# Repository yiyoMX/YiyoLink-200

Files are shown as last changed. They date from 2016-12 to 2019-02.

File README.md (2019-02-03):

# YiyoLink-200
TI CC1111 BLE BRIDGE

What is it?
A SMART Bluetooth 4.2 LE module based on nrf51822, it allows for a Texas Instruments CC-1111 USB DNGL to communicate to any BLE compatible device. It can act as a transparent UART bridge.

How does it works?
Simply plug in the CC-1111 with the header pins. You could also plug jumper wires to connect any device via UART. Can flash firmware to BLE module via OTA, using an Iphone.

Features?
- TI-CC1111 header pins compatible socket.
- 2-pin JST-PH battery connector.
- Micro USB Lithium-ion battery charger.
- Charging led indicator (goes off when fully charged).
- Smart BLE 4.2 BMD-200.
- BLE connected indicator.
- On/Off switch.
- Exposed pwr pads to solder external charging source. (wireless charging? - not tested)
- Small footprint.

Limitations.
-Due to the version of BLE, only 20 bytes are allowed per write.

How does it looks?
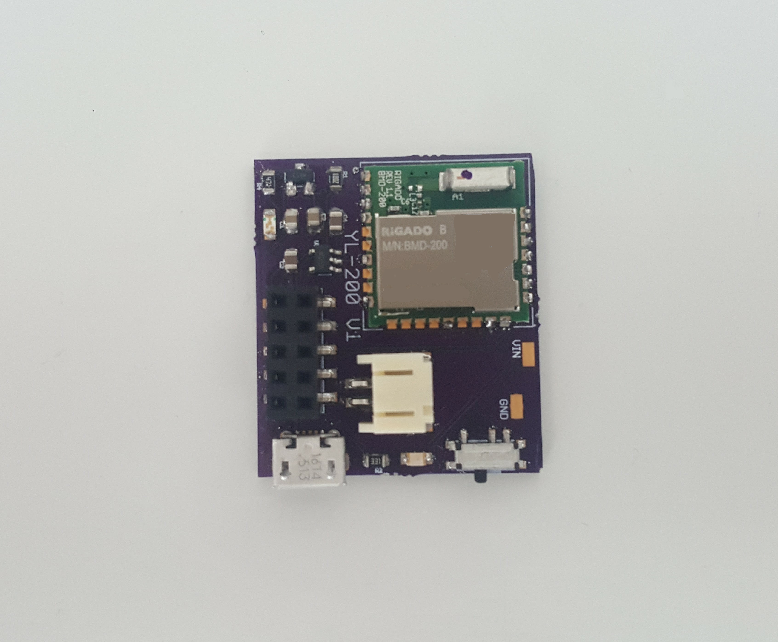
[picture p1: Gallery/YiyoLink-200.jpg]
YiyoLink-200-v1


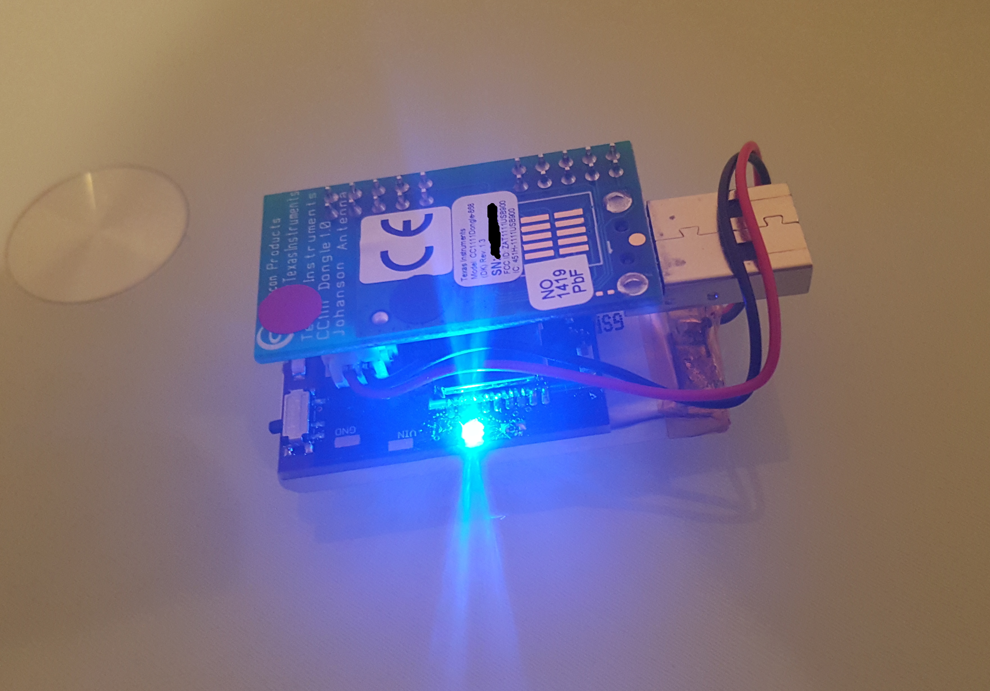
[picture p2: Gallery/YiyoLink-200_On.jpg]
YiyoLink-200 On


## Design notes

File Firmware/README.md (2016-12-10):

This is the firmware for the BLE module. It acts as a transparent UART bridge.

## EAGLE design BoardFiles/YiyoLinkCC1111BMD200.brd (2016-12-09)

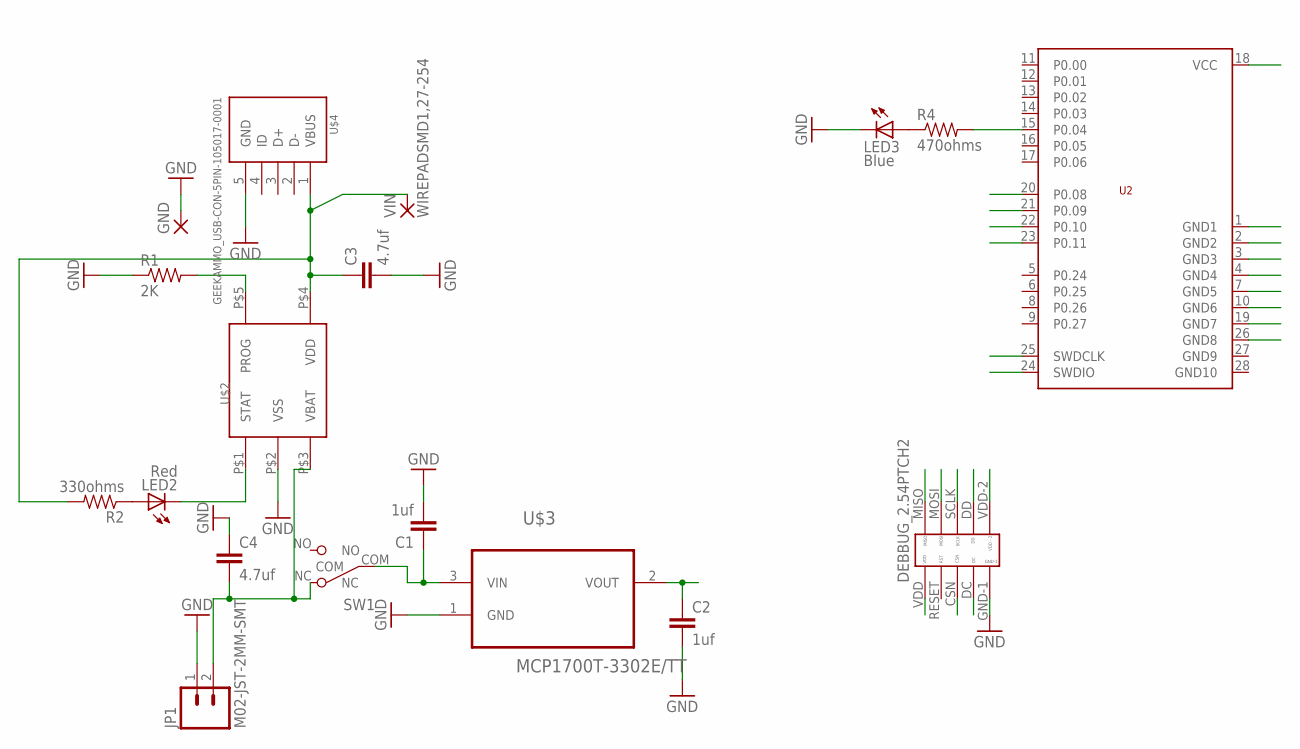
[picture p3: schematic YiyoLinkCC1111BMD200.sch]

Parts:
C1, C2: 1uf; 0805-CAP
C3, C4: 4.7uf; 0805
DEBBUG_2.54PTCH2: YIYOSLIBRARY_5X2_HEADER; YIYOSLIBRARY_5X2_FEMALE_HEADER
GND: WIREPADSMD1,27-254; SMD1,27-2,54
JP1: M02-JST-2MM-SMT; JST-2-SMD
LED2: Red; SML0805
LED3: Blue; SML0805
R1: 2K; 0805
R2: 330ohms; 0805
R4: 470ohms; 0805
SW1: SW_SLIDE; SLIDE_SWITCH_SMD
U2: BMD-200
U$2: MCP73831; 5PIN_SOT23
U$3: MCP1700T-3302E/TT; SOT95P237X112-3N
U$4: GEEKAMMO_USB-CON-5PIN-105017-0001; GEEKAMMO_USB-MICRO-MOLEX-105017-0001
VIN: WIREPADSMD1,27-254; SMD1,27-2,54

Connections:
CSN: DEBBUG_2.54PTCH2.CSN, U2.20 (P0.08)
DC: DEBBUG_2.54PTCH2.DC, U2.25 (SWDCLK)
DD: DEBBUG_2.54PTCH2.DD, U2.24 (SWDIO)
GND: C1.2, C2.2, C3.2, C4.1, DEBBUG_2.54PTCH2.GND-1, GND.1, JP1.1 (2), LED3.C, R1.1, U2.1 (GND1), U2.2 (GND2), U2.3 (GND3), U2.4 (GND4), U2.7 (GND5), U2.10 (GND6), U2.19 (GND7), U2.26 (GND8), U$2.P$2 (VSS), U$3.1 (GND), U$4.5 (GND)
MISO: DEBBUG_2.54PTCH2.MISO, U2.22 (P0.10)
MOSI: DEBBUG_2.54PTCH2.MOSI, U2.21 (P0.09)
unnamed: LED3.A, R4.1
unnamed: R4.2, U2.15 (P0.04)
unnamed: LED2.A, R2.1
unnamed: C3.1, R2.2, U$2.P$4 (VDD), U$4.1 (VBUS), VIN.1
unnamed: R1.2, U$2.P$5 (PROG)
unnamed: C4.2, JP1.2 (1), SW1.NC, U$2.P$3 (VBAT)
unnamed: C1.1, SW1.COM, U$3.3 (VIN)
unnamed: LED2.C, U$2.P$1 (STAT)
SCLK: DEBBUG_2.54PTCH2.SCLK, U2.23 (P0.11)
VDDO: C2.1, DEBBUG_2.54PTCH2.VDD, DEBBUG_2.54PTCH2.VDD-2, U2.18 (VCC), U$3.2 (VOUT)

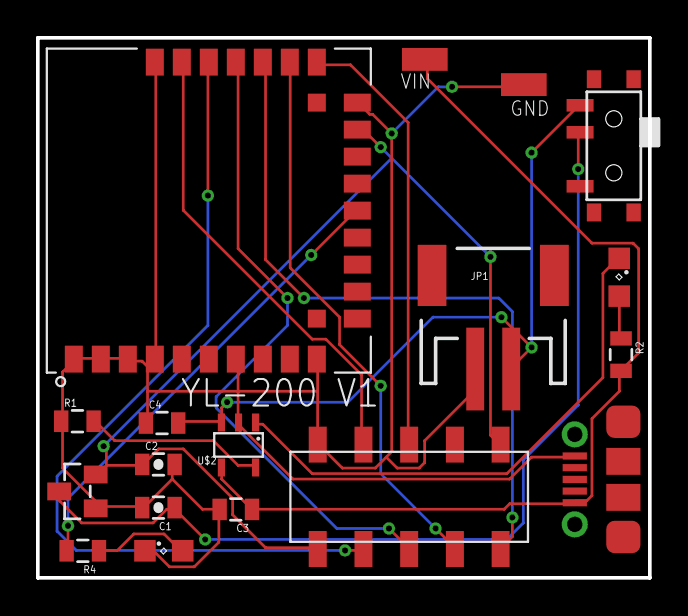
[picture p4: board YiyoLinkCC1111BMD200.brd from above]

Board: 2 copper layers, 34.0 x 30.0 mm, 18 parts (0 on the bottom side), 16 nets.

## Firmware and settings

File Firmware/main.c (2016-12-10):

/* Copyright (c) 2014 Nordic Semiconductor. All Rights Reserved.
 *
 * The information contained herein is property of Nordic Semiconductor ASA.
 * Terms and conditions of usage are described in detail in NORDIC
 * SEMICONDUCTOR STANDARD SOFTWARE LICENSE AGREEMENT.
 *
 * Licensees are granted free, non-transferable use of the information. NO
 * WARRANTY of ANY KIND is provided. This heading must NOT be removed from
 * the file.
 *
 */

/** @file
 *
 * @defgroup ble_sdk_app_template_main main.c
 * @{
 * @ingroup ble_sdk_app_template
 * @brief Template project main file.
 *
 * This file contains a template for creating a new application. It has the code necessary to wakeup
 * from button, advertise, get a connection restart advertising on disconnect and if no new
 * connection created go back to system-off mode.
 * It can easily be used as a starting point for creating a new application, the comments identified
 * with 'YOUR_JOB' indicates where and how you can customize.
 */

#include <stdint.h>
#include <string.h>
#include "nordic_common.h"
#include "nrf.h"
#include "app_error.h"
#include "ble.h"
#include "ble_hci.h"
#include "ble_srv_common.h"
#include "ble_advdata.h"
#include "ble_advertising.h"
#include "ble_conn_params.h"
#include "boards.h"
#include "softdevice_handler.h"
#include "app_timer.h"
#include "device_manager.h"
#include "pstorage.h"
#include "app_trace.h"
#include "bsp.h"
#include "bsp_btn_ble.h"

//Agregadas
#include "ble_nus.h"
#include "app_uart.h"

#define IS_SRVC_CHANGED_CHARACT_PRESENT  1                                          /**< Include or not the service_changed characteristic. if not enabled, the server's database cannot be changed for the lifetime of the device*/
#define CONNECTED_LED_PIN_NO 			BSP_LED_0
#define DEVICE_NAME                      "Yiyo-Link_200-TEST"                            /**< Name of device. Will be included in the advertising data. */
#define MANUFACTURER_NAME                "NordicSemiconductor"                      /**< Manufacturer. Will be passed to Device Information Service. */
#define APP_ADV_INTERVAL                 300                                        /**< The advertising interval (in units of 0.625 ms. This value corresponds to 25 ms). */
#define APP_ADV_TIMEOUT_IN_SECONDS       0                                       /**< The advertising timeout in units of seconds. */

#define APP_TIMER_PRESCALER              0                                          /**< Value of the RTC1 PRESCALER register. */
#define APP_TIMER_OP_QUEUE_SIZE          4                                          /**< Size of timer operation queues. */

#define MIN_CONN_INTERVAL                MSEC_TO_UNITS(100, UNIT_1_25_MS)           /**< Minimum acceptable connection interval (0.1 seconds). */
#define MAX_CONN_INTERVAL                MSEC_TO_UNITS(200, UNIT_1_25_MS)           /**< Maximum acceptable connection interval (0.2 second). */
#define SLAVE_LATENCY                    0                                          /**< Slave latency. */
#define CONN_SUP_TIMEOUT                 MSEC_TO_UNITS(4000, UNIT_10_MS)            /**< Connection supervisory timeout (4 seconds). */

#define FIRST_CONN_PARAMS_UPDATE_DELAY   APP_TIMER_TICKS(5000, APP_TIMER_PRESCALER) /**< Time from initiating event (connect or start of notification) to first time sd_ble_gap_conn_param_update is called (5 seconds). */
#define NEXT_CONN_PARAMS_UPDATE_DELAY    APP_TIMER_TICKS(30000, APP_TIMER_PRESCALER)/**< Time between each call to sd_ble_gap_conn_param_update after the first call (30 seconds). */
#define MAX_CONN_PARAMS_UPDATE_COUNT     3                                          /**< Number of attempts before giving up the connection parameter negotiation. */

#define SEC_PARAM_BOND                   0                                          /**< Perform bonding. */
#define SEC_PARAM_MITM                   0                                          /**< Man In The Middle protection not required. */
#define SEC_PARAM_IO_CAPABILITIES        BLE_GAP_IO_CAPS_NONE                       /**< No I/O capabilities. */
#define SEC_PARAM_OOB                    0                                          /**< Out Of Band data not available. */
#define SEC_PARAM_MIN_KEY_SIZE           7                                          /**< Minimum encryption key size. */
#define SEC_PARAM_MAX_KEY_SIZE           16                                         /**< Maximum encryption key size. */

#define START_STRING                    "Start.."

#define DEAD_BEEF                        0xDEADBEEF                                 /**< Value used as error code on stack dump, can be used to identify stack location on stack unwind. */

#define UART_TX_BUF_SIZE                256                                         /**< UART TX buffer size. */
#define UART_RX_BUF_SIZE                256                                         /**< UART RX buffer size. */

static dm_application_instance_t        m_app_handle;                               /**< Application identifier allocated by device manager */
static ble_nus_t                        m_nus; 																			/**< Structure to identify the Nordic UART Service. */
static uint16_t                          m_conn_handle = BLE_CONN_HANDLE_INVALID;   /**< Handle of the current connection. */

/* YOUR_JOB: Declare all services structure your application is using
static ble_xx_service_t                     m_xxs;
static ble_yy_service_t                     m_yys;
*/

// YOUR_JOB: Use UUIDs for service(s) used in your application.
static ble_uuid_t m_adv_uuids[] = {{BLE_UUID_DEVICE_INFORMATION_SERVICE, BLE_UUID_TYPE_BLE}}; /**< Universally unique service identifiers. */

                                   
/**@brief Callback function for asserts in the SoftDevice.
 *
 * @details This function will be called in case of an assert in the SoftDevice.
 *
 * @warning This handler is an example only and does not fit a final product. You need to analyze
 *          how your product is supposed to react in case of Assert.
 * @warning On assert from the SoftDevice, the system can only recover on reset.
 *
 * @param[in] line_num   Line number of the failing ASSERT call.
 * @param[in] file_name  File name of the failing ASSERT call.
 */
void assert_nrf_callback(uint16_t line_num, const uint8_t * p_file_name)
{
    app_error_handler(DEAD_BEEF, line_num, p_file_name);
}


/**@brief Function for the Timer initialization.
 *
 * @details Initializes the timer module. This creates and starts application timers.
 */
static void timers_init(void)
{

    // Initialize timer module.
    APP_TIMER_INIT(APP_TIMER_PRESCALER, APP_TIMER_OP_QUEUE_SIZE, false);

    // Create timers.

    /* YOUR_JOB: Create any timers to be used by the application.
                 Below is an example of how to create a timer.
                 For every new timer needed, increase the value of the macro APP_TIMER_MAX_TIMERS by
                 one.
    uint32_t err_code;
    err_code = app_timer_create(&m_app_timer_id, APP_TIMER_MODE_REPEATED, timer_timeout_handler);
    APP_ERROR_CHECK(err_code); */
}


/**@brief Function for the GAP initialization.
 *
 * @details This function sets up all the necessary GAP (Generic Access Profile) parameters of the
 *          device including the device name, appearance, and the preferred connection parameters.
 */
static void gap_params_init(void)
{
    uint32_t                err_code;
    ble_gap_conn_params_t   gap_conn_params;
    ble_gap_conn_sec_mode_t sec_mode;

    BLE_GAP_CONN_SEC_MODE_SET_OPEN(&sec_mode);

    err_code = sd_ble_gap_device_name_set(&sec_mode,
                                          (const uint8_t *)DEVICE_NAME,
                                          strlen(DEVICE_NAME));
    APP_ERROR_CHECK(err_code);

    /* YOUR_JOB: Use an appearance value matching the application's use case.
    err_code = sd_ble_gap_appearance_set(BLE_APPEARANCE_);
    APP_ERROR_CHECK(err_code); */

    memset(&gap_conn_params, 0, sizeof(gap_conn_params));

    gap_conn_params.min_conn_interval = MIN_CONN_INTERVAL;
    gap_conn_params.max_conn_interval = MAX_CONN_INTERVAL;
    gap_conn_params.slave_latency     = SLAVE_LATENCY;
    gap_conn_params.conn_sup_timeout  = CONN_SUP_TIMEOUT;

    err_code = sd_ble_gap_ppcp_set(&gap_conn_params);
    APP_ERROR_CHECK(err_code);
}


/**@brief Function for handling the YYY Service events. 
 * YOUR_JOB implement a service handler function depending on the event the service you are using can generate
 *
 * @details This function will be called for all YY Service events which are passed to
 *          the application.
 *
 * @param[in]   p_yy_service   YY Service structure.
 * @param[in]   p_evt          Event received from the YY Service.
 *
 *
static void on_yys_evt(ble_yy_service_t     * p_yy_service, 
                       ble_yy_service_evt_t * p_evt)
{
    switch (p_evt->evt_type)
    {
        case BLE_YY_NAME_EVT_WRITE:
            APPL_LOG("[APPL]: charact written with value %s. \r\n", p_evt->params.char_xx.value.p_str);
            break;
        
        default:
            // No implementation needed.
            break;
    }
}*/

/**@brief Function for handling the data from the Nordic UART Service.
 *
 * @details This function will process the data received from the Nordic UART BLE Service and send
 *          it to the UART module.
 *
 * @param[in] p_nus    Nordic UART Service structure.
 * @param[in] p_data   Data to be send to UART module.
 * @param[in] length   Length of the data.
 */
/**@snippet [Handling the data received over BLE] */
static void nus_data_handler(ble_nus_t * p_nus, uint8_t * p_data, uint16_t length)
{
//		nrf_gpio_pin_toggle(CONNECTED_LED_PIN_NO);
    for (uint32_t i = 0; i < length; i++)
    {
//        while(app_uart_put(p_data[i]) != NRF_SUCCESS);
			app_uart_put(p_data[i]);
    }
//    while(app_uart_put('\n') != NRF_SUCCESS);
}
/**@snippet [Handling the data received over BLE] */
/**@brief Function for initializing services that will be used by the application.
 */


static void services_init(void)
{
	uint32_t       err_code;
		
    ble_nus_init_t nus_init;
		memset(&nus_init, 0, sizeof(nus_init));

    nus_init.data_handler = nus_data_handler;
    
    err_code = ble_nus_init(&m_nus, &nus_init);
    APP_ERROR_CHECK(err_code);
    /* YOUR_JOB: Add code to initialize the services used by the application.
    uint32_t                           err_code;
    ble_xxs_init_t                     xxs_init;
    ble_yys_init_t                     yys_init;

    // Initialize XXX Service.
    memset(&xxs_init, 0, sizeof(xxs_init));

    xxs_init.evt_handler                = NULL;
    xxs_init.is_xxx_notify_supported    = true;
    xxs_init.ble_xx_initial_value.level = 100; 
    
    err_code = ble_bas_init(&m_xxs, &xxs_init);
    APP_ERROR_CHECK(err_code);

    // Initialize YYY Service.
    memset(&yys_init, 0, sizeof(yys_init));
    yys_init.evt_handler                  = on_yys_evt;
    yys_init.ble_yy_initial_value.counter = 0;

    err_code = ble_yy_service_init(&yys_init, &yy_init);
    APP_ERROR_CHECK(err_code);
    */
}


void uart_putstring(const uint8_t * str)

{

    uint32_t err_code;
    uint8_t len = strlen((char *) str);
    for (uint8_t i = 0; i < len; i++)
    {
        err_code = app_uart_put(str[i]);
        APP_ERROR_CHECK(err_code);
    }
}

/**@brief Function for handling the Connection Parameters Module.
 *
 * @details This function will be called for all events in the Connection Parameters Module which
 *          are passed to the application.
 *          @note All this function does is to disconnect. This could have been done by simply
 *                setting the disconnect_on_fail config parameter, but instead we use the event
 *                handler mechanism to demonstrate its use.
 *
 * @param[in] p_evt  Event received from the Connection Parameters Module.
 */
static void on_conn_params_evt(ble_conn_params_evt_t * p_evt)
{
    uint32_t err_code;

    if (p_evt->evt_type == BLE_CONN_PARAMS_EVT_FAILED)
    {
        err_code = sd_ble_gap_disconnect(m_conn_handle, BLE_HCI_CONN_INTERVAL_UNACCEPTABLE);
        APP_ERROR_CHECK(err_code);
    }
}


/**@brief Function for handling a Connection Parameters error.
 *
 * @param[in] nrf_error  Error code containing information about what went wrong.
 */
static void conn_params_error_handler(uint32_t nrf_error)
{
    APP_ERROR_HANDLER(nrf_error);
}


/**@brief Function for initializing the Connection Parameters module.
 */
static void conn_params_init(void)
{
    uint32_t               err_code;
    ble_conn_params_init_t cp_init;

    memset(&cp_init, 0, sizeof(cp_init));

    cp_init.p_conn_params                  = NULL;
    cp_init.first_conn_params_update_delay = FIRST_CONN_PARAMS_UPDATE_DELAY;
    cp_init.next_conn_params_update_delay  = NEXT_CONN_PARAMS_UPDATE_DELAY;
    cp_init.max_conn_params_update_count   = MAX_CONN_PARAMS_UPDATE_COUNT;
    cp_init.start_on_notify_cccd_handle    = BLE_GATT_HANDLE_INVALID;
    cp_init.disconnect_on_fail             = false;
    cp_init.evt_handler                    = on_conn_params_evt;
    cp_init.error_handler                  = conn_params_error_handler;

    err_code = ble_conn_params_init(&cp_init);
    APP_ERROR_CHECK(err_code);
}


/**@brief Function for starting timers.
*/
static void application_timers_start(void)
{
    /* YOUR_JOB: Start your timers. below is an example of how to start a timer.
    uint32_t err_code;
    err_code = app_timer_start(m_app_timer_id, TIMER_INTERVAL, NULL);
    APP_ERROR_CHECK(err_code); */
   
}


/**@brief Function for putting the chip into sleep mode.
 *
 * @note This function will not return.
 */
static void sleep_mode_enter(void)
{
    uint32_t err_code = bsp_indication_set(BSP_INDICATE_IDLE);
    APP_ERROR_CHECK(err_code);

    // Prepare wakeup buttons.
    err_code = bsp_btn_ble_sleep_mode_prepare();
    APP_ERROR_CHECK(err_code);

    // Go to system-off mode (this function will not return; wakeup will cause a reset).
    err_code = sd_power_system_off();
    APP_ERROR_CHECK(err_code);
}


/**@brief Function for handling advertising events.
 *
 * @details This function will be called for advertising events which are passed to the application.
 *
 * @param[in] ble_adv_evt  Advertising event.
 */
static void on_adv_evt(ble_adv_evt_t ble_adv_evt)
{
    uint32_t err_code;

    switch (ble_adv_evt)
    {
        case BLE_ADV_EVT_FAST:
            err_code = bsp_indication_set(BSP_INDICATE_ADVERTISING);
            APP_ERROR_CHECK(err_code);
            break;
        case BLE_ADV_EVT_IDLE:
            //sleep_mode_enter();
            break;
        default:
            break;
    }
}


/**@brief Function for handling the Application's BLE Stack events.
 *
 * @param[in] p_ble_evt  Bluetooth stack event.
 */
static void on_ble_evt(ble_evt_t * p_ble_evt)
{
    uint32_t err_code;

    switch (p_ble_evt->header.evt_id)
            {
        case BLE_GAP_EVT_CONNECTED:
						nrf_gpio_pin_set(CONNECTED_LED_PIN_NO);
            err_code = bsp_indication_set(BSP_INDICATE_CONNECTED);
            APP_ERROR_CHECK(err_code);
            m_conn_handle = p_ble_evt->evt.gap_evt.conn_handle;
            break;

        case BLE_GAP_EVT_DISCONNECTED:
						nrf_gpio_pin_clear(CONNECTED_LED_PIN_NO);
            m_conn_handle = BLE_CONN_HANDLE_INVALID;
            break;
				
				

        default:
            // No implementation needed.
            break;
    }
}


/**@brief Function for dispatching a BLE stack event to all modules with a BLE stack event handler.
 *
 * @details This function is called from the BLE Stack event interrupt handler after a BLE stack
 *          event has been received.
 *
 * @param[in] p_ble_evt  Bluetooth stack event.
 */
static void ble_evt_dispatch(ble_evt_t * p_ble_evt)
{
    dm_ble_evt_handler(p_ble_evt);
    ble_conn_params_on_ble_evt(p_ble_evt);
		ble_nus_on_ble_evt(&m_nus, p_ble_evt);
    bsp_btn_ble_on_ble_evt(p_ble_evt);
    on_ble_evt(p_ble_evt);
    ble_advertising_on_ble_evt(p_ble_evt);
    /*YOUR_JOB add calls to _on_ble_evt functions from each service your application is using
    ble_xxs_on_ble_evt(&m_xxs, p_ble_evt);
    ble_yys_on_ble_evt(&m_yys, p_ble_evt);
    */
}


/**@brief Function for dispatching a system event to interested modules.
 *
 * @details This function is called from the System event interrupt handler after a system
 *          event has been received.
 *
 * @param[in] sys_evt  System stack event.
 */
static void sys_evt_dispatch(uint32_t sys_evt)
{
    pstorage_sys_event_handler(sys_evt);
    ble_advertising_on_sys_evt(sys_evt);
}


/**@brief Function for initializing the BLE stack.
 *
 * @details Initializes the SoftDevice and the BLE event interrupt.
 */
static void ble_stack_init(void)
{
    uint32_t err_code;

    // Initialize the SoftDevice handler module.
SOFTDEVICE_HANDLER_INIT(NRF_CLOCK_LFCLKSRC_RC_250_PPM_TEMP_4000MS_CALIBRATION, false);
	
#if defined(S110) || defined(S130) || defined(S132)
    // Enable BLE stack.
    ble_enable_params_t ble_enable_params;
    memset(&ble_enable_params, 0, sizeof(ble_enable_params));
#if (defined(S130) || defined(S132))
    ble_enable_params.gatts_enable_params.attr_tab_size   = BLE_GATTS_ATTR_TAB_SIZE_DEFAULT;
#endif
    ble_enable_params.gatts_enable_params.service_changed = IS_SRVC_CHANGED_CHARACT_PRESENT;
    err_code = sd_ble_enable(&ble_enable_params);
    APP_ERROR_CHECK(err_code);
#endif

    // Register with the SoftDevice handler module for BLE events.
    err_code = softdevice_ble_evt_handler_set(ble_evt_dispatch);
    APP_ERROR_CHECK(err_code);

   
}


/**@brief Function for handling events from the BSP module.
 *
 * @param[in]   event   Event generated by button press.
 */
void bsp_event_handler(bsp_event_t event)
{
    uint32_t err_code;
    switch (event)
    {
        case BSP_EVENT_SLEEP:
            //sleep_mode_enter();
            break;

        case BSP_EVENT_DISCONNECT:
            err_code = sd_ble_gap_disconnect(m_conn_handle, BLE_HCI_REMOTE_USER_TERMINATED_CONNECTION);
            if (err_code != NRF_ERROR_INVALID_STATE)
            {
                APP_ERROR_CHECK(err_code);
            }
            break;

        case BSP_EVENT_WHITELIST_OFF:
            err_code = ble_advertising_restart_without_whitelist();
            if (err_code != NRF_ERROR_INVALID_STATE)
            {
                APP_ERROR_CHECK(err_code);
            }
            break;

        default:
            break;
    }
}


/**@brief   Function for handling app_uart events.
 *
 * @details This function will receive a single character from the app_uart module and append it to 
 *          a string. The string will be be sent over BLE when the last character received was a 
 *          'new line' i.e '\n' (hex 0x0D) or if the string has reached a length of 
 *          @ref NUS_MAX_DATA_LENGTH.
 */
/**@snippet [Handling the data received over UART] */
void uart_event_handle(app_uart_evt_t * p_event)
{
	  
    static uint8_t data_array[BLE_NUS_MAX_DATA_LEN];
    static uint8_t index = 0;
    uint32_t       err_code;

    switch (p_event->evt_type)
    {
        case APP_UART_DATA_READY:
            UNUSED_VARIABLE(app_uart_get(&data_array[index]));
            index++;
//						nrf_gpio_pin_set(CONNECTED_LED_PIN_NO);
//            if ((data_array[index - 1] == '\n') || (index >= (BLE_NUS_MAX_DATA_LEN)))
				if (( data_array[index - 1] == '\x00') || (index >= (BLE_NUS_MAX_DATA_LEN)))
            {
							
                err_code = ble_nus_string_send(&m_nus, data_array, index);
                if (err_code != NRF_ERROR_INVALID_STATE)
                {
                    APP_ERROR_CHECK(err_code);
                }
                index = 0;
            }
            break;

        case APP_UART_COMMUNICATION_ERROR:
					//nrf_gpio_pin_set(CONNECTED_LED_PIN_NO);
            APP_ERROR_HANDLER(p_event->data.error_communication);
            break;

        case APP_UART_FIFO_ERROR:
					//nrf_gpio_pin_set(CONNECTED_LED_PIN_NO);
            APP_ERROR_HANDLER(p_event->data.error_code);
            break;

        default:
            break;
    }
}
/**@snippet [Handling the data received over UART] */


/**@brief  Function for initializing the UART module.
 */
/**@snippet [UART Initialization] */
static void uart_init(void)
{
    uint32_t                     err_code;
    const app_uart_comm_params_t comm_params =
    {
        RX_PIN_NUMBER,
        TX_PIN_NUMBER,
        RTS_PIN_NUMBER,
        CTS_PIN_NUMBER,
        APP_UART_FLOW_CONTROL_ENABLED,
        false,
        UART_BAUDRATE_BAUDRATE_Baud19200
    };

    APP_UART_FIFO_INIT( &comm_params,
                       UART_RX_BUF_SIZE,
                       UART_TX_BUF_SIZE,
                       uart_event_handle,
                       APP_IRQ_PRIORITY_LOW,
                       err_code);
    APP_ERROR_CHECK(err_code);
}
/**@snippet [UART Initialization] */




/**@brief Function for handling the Device Manager events.
 *
 * @param[in] p_evt  Data associated to the device manager event.
 */
static uint32_t device_manager_evt_handler(dm_handle_t const * p_handle,
                                           dm_event_t const  * p_event,
                                           ret_code_t        event_result)
{
    APP_ERROR_CHECK(event_result);
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
int main(void)
{
    uint32_t err_code;
    bool erase_bonds;

    // Initialize.
    timers_init();
	
	//YO
		uart_init();
    buttons_leds_init(&erase_bonds);
    ble_stack_init();
    device_manager_init(erase_bonds);
    gap_params_init();
		services_init();
    advertising_init();
    conn_params_init();

    // Start execution.
    application_timers_start();
    err_code = ble_advertising_start(BLE_ADV_MODE_FAST);
    APP_ERROR_CHECK(err_code);

    // Enter main loop.
    for (;;)
    {
        power_manage();
    }
}

/**
 * @}
 */

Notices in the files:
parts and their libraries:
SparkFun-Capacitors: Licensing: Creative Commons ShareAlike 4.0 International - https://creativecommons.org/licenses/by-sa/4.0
